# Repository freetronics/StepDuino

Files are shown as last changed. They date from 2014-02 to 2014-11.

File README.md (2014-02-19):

Freetronics StepDuino
=====================
Copyright 2013 Freetronics Pty Ltd  
Freetronics site:  www.freetronics.com  
Freetronics email: info@freetronics.com  

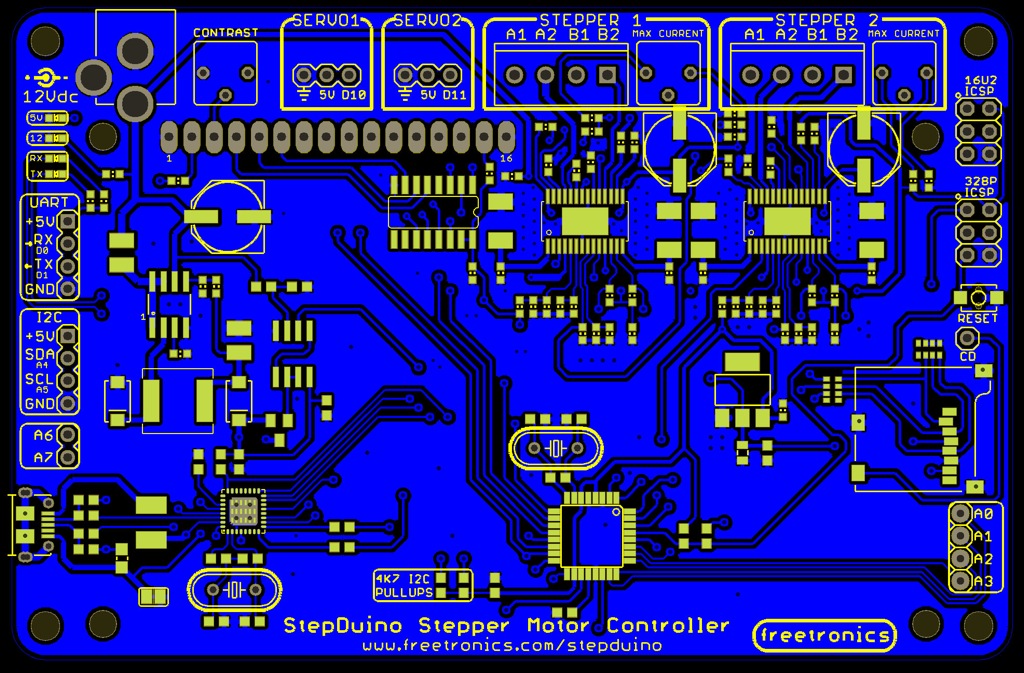
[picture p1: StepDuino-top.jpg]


The StepDuino is an Arduino-compatible board with two onboard stepper
motor drivers, a 20x4 LCD, servo outputs, and an SD card slot. This
makes it ideal for mechatronics projects such as small robots or 2D
plotters.

It uses the same ATmega328P MCU as the Arduino Uno reference design,
and includes an ATmega16u2 USB-to-serial converter just like the Uno.
You can therefore program it the same way as you would an Uno, but
with the benefit of all the extra features built in to the StepDuino.

Features:

 * 2 x 4-wire stepper motor drivers
 * 20x4 LCD
 * Micro SD card slot
 * Analog inputs for use with Nintendo DS touch screen or other sensors

You can view more online at:

  http://www.freetronics.com/stepduino

INSTALLATION
------------
The design is saved as an EAGLE project. EAGLE PCB design software is
available from www.cadsoftusa.com free for non-commercial use. To use
this project download it and place the directory containing these files
into the "eagle" directory on your computer. Then open EAGLE and
navigate to Projects -> eagle -> StepDuino.

DISTRIBUTION
------------
The specific terms of distribution of this project are governed by the
license referenced below.

LICENSE
-------
Licensed under the TAPR Open Hardware License (www.tapr.org/OHL).
The "license" folder within this repository also contains a copy of
this license in plain text format.

CREDITS
-------
Designed by Luke Weston (reindeerflotilla@gmail.com) and Jonathan Oxer
(jon@freetronics.com)

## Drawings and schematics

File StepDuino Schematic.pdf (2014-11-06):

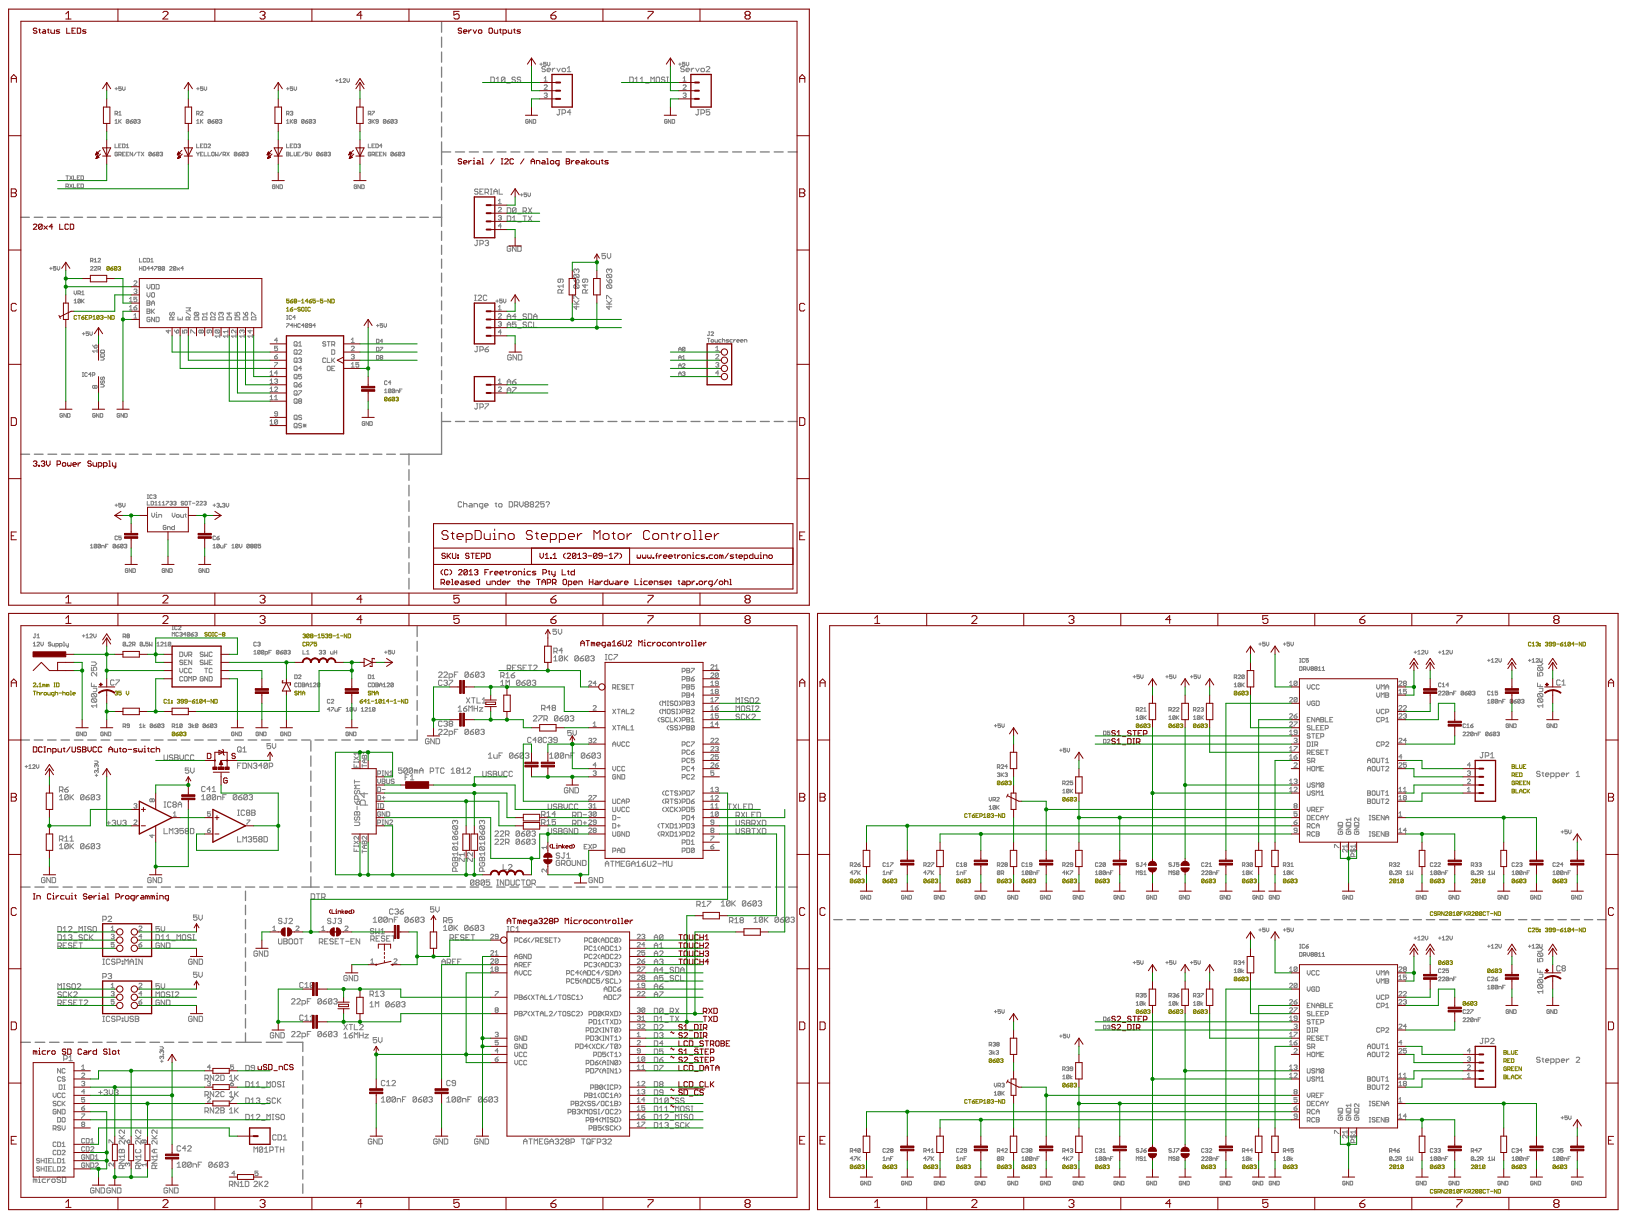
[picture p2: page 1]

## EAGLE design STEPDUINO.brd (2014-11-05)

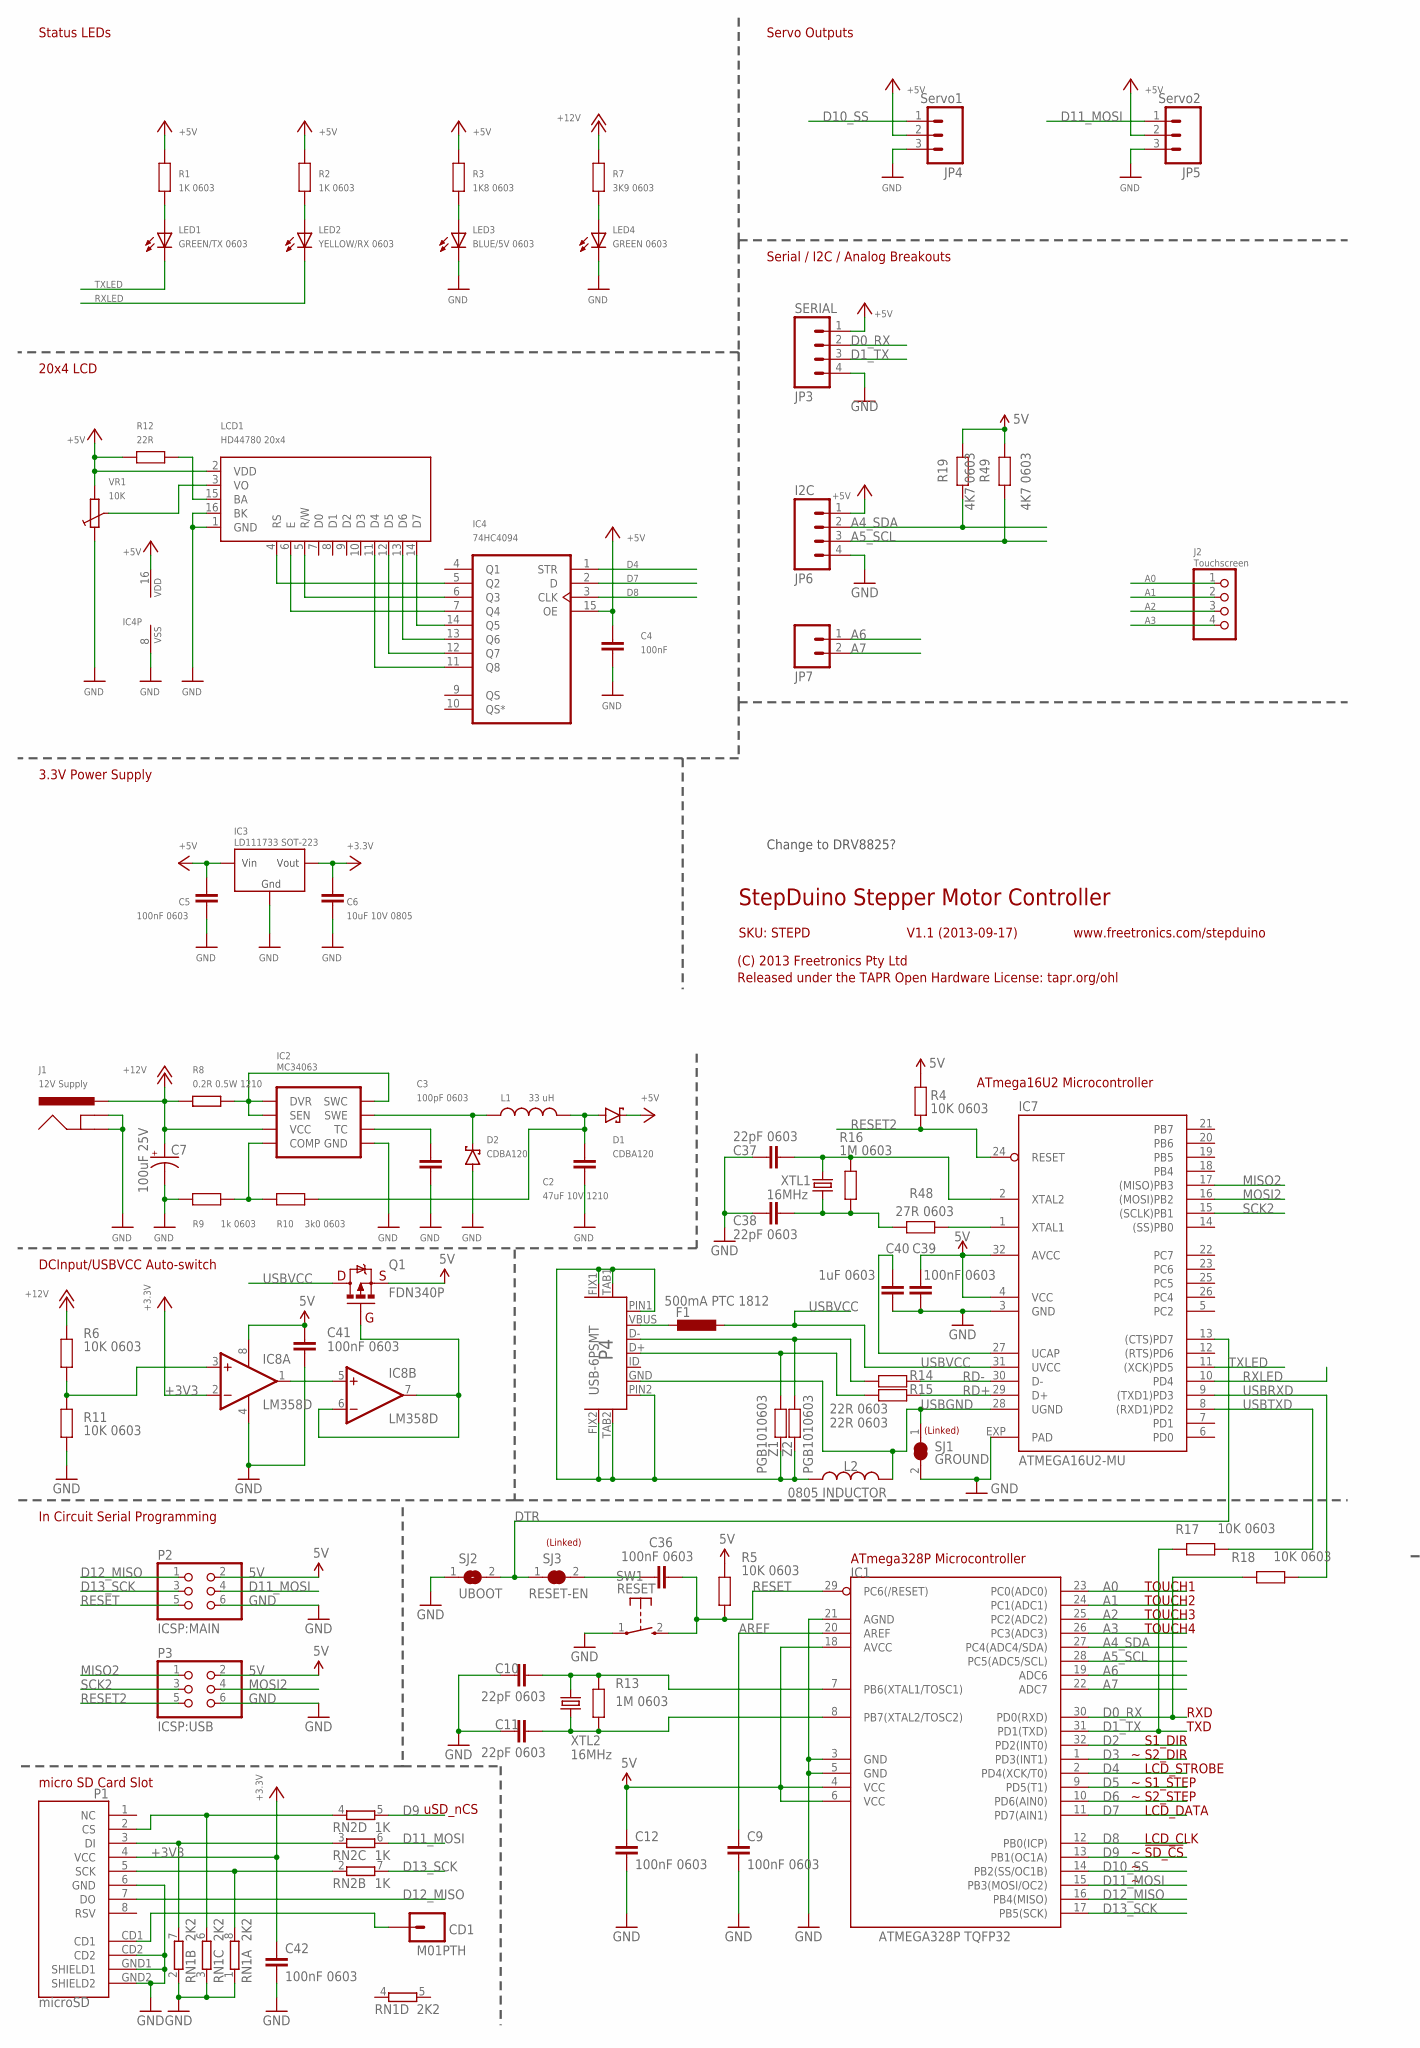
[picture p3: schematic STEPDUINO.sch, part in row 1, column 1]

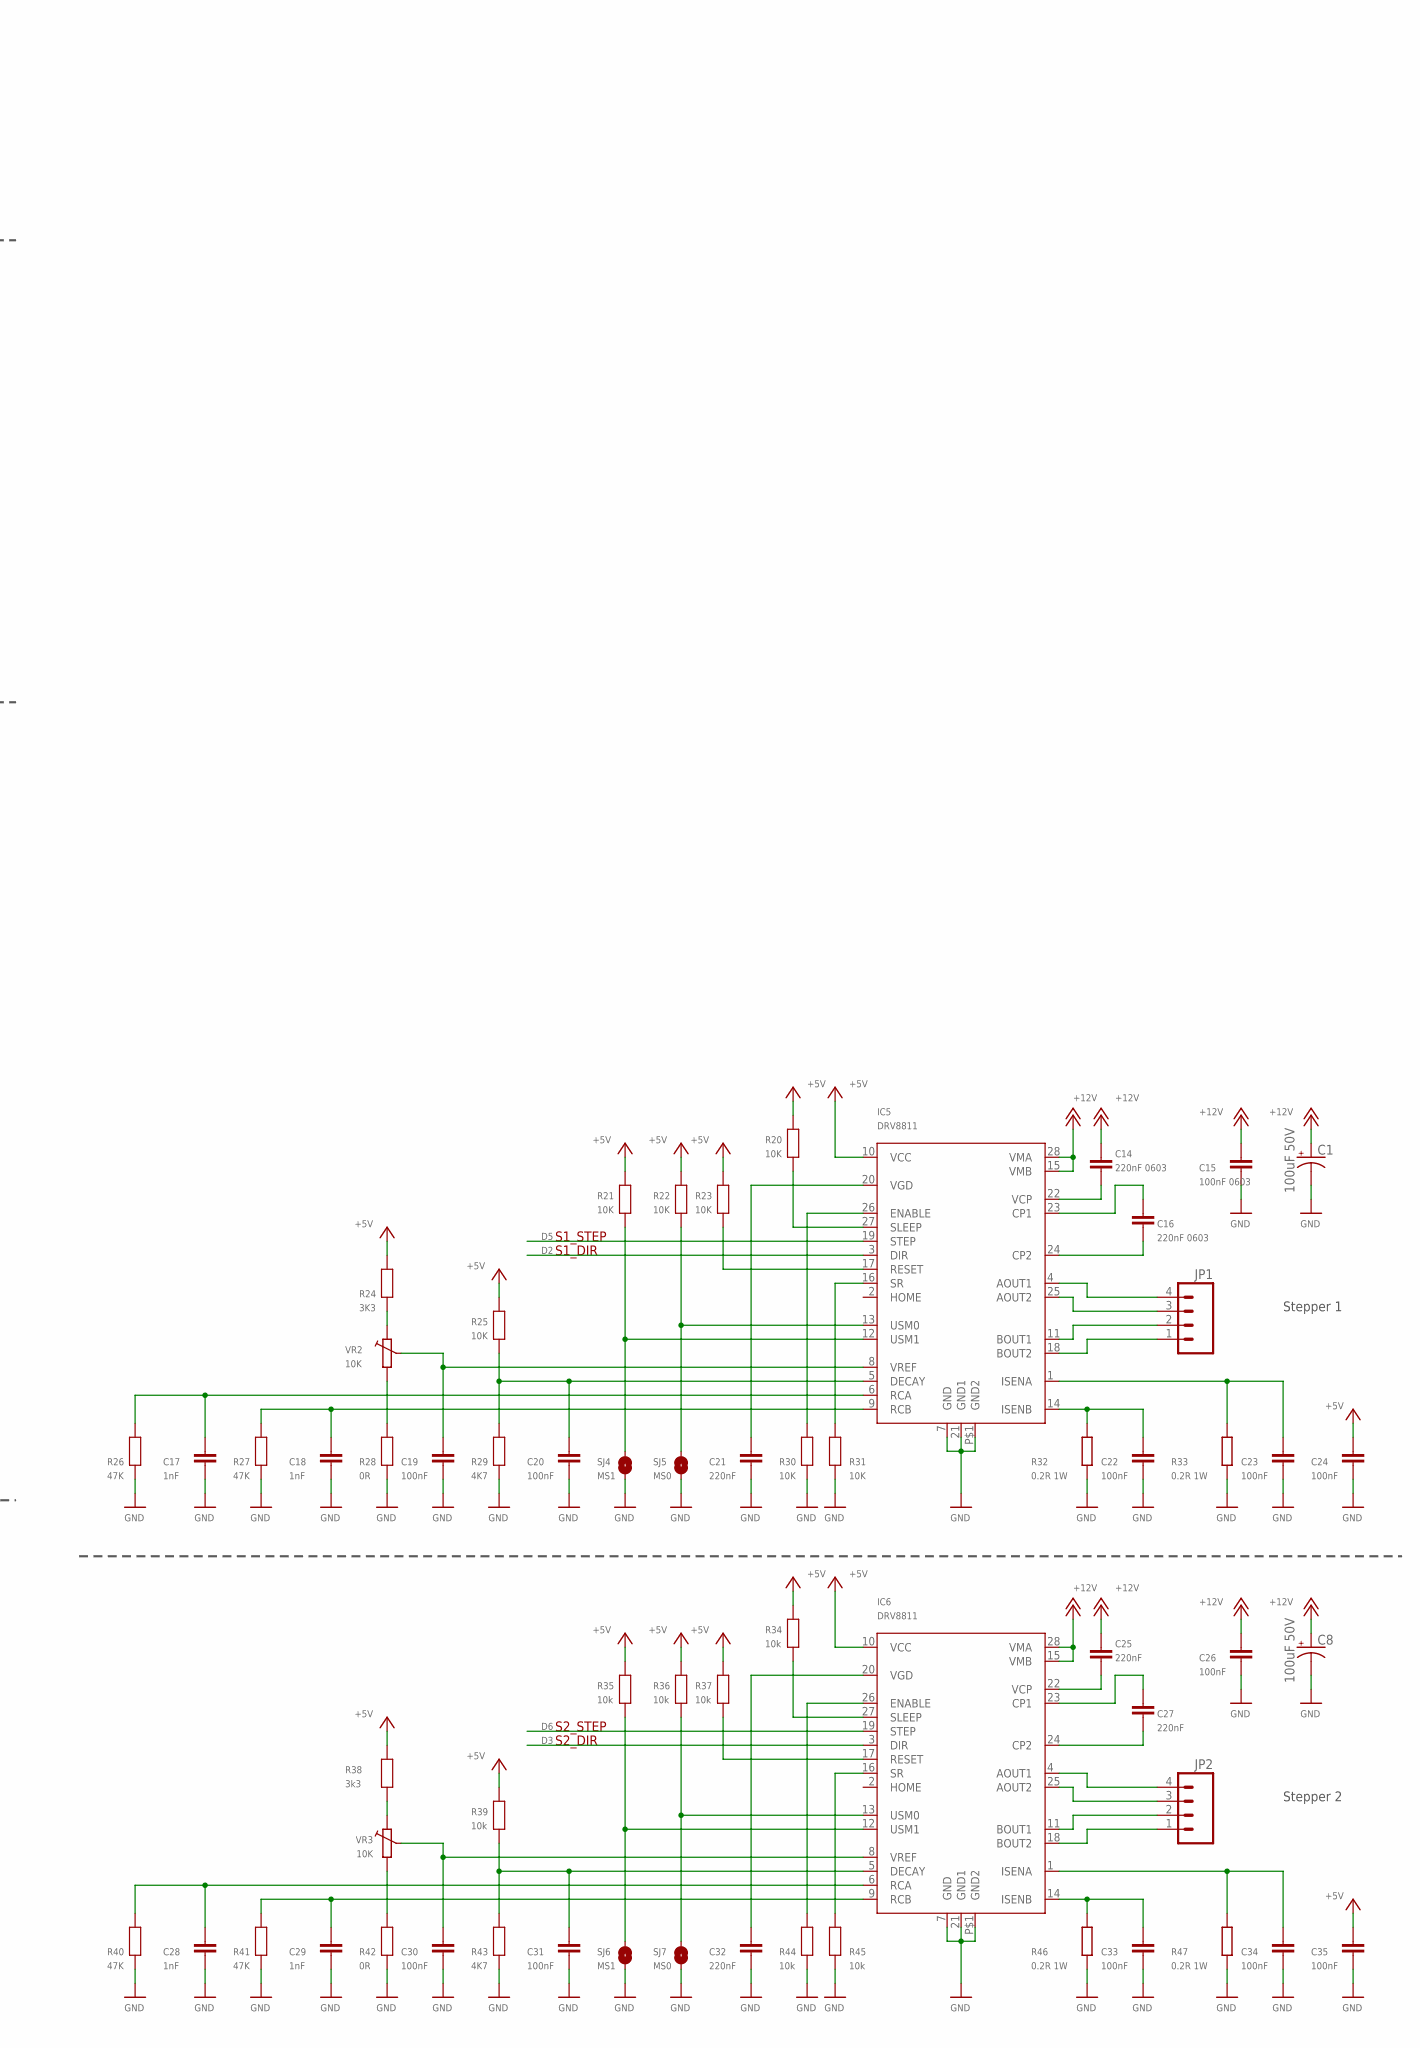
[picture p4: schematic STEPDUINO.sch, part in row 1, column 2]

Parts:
C1, C8: 100uF 50V; PANASONIC_E
C2: 47uF 10V 1210; C1210
C3: 100pF 0603; 0603
C4, C19, C20, C22, C23, C24, C26, C30, C31, C33, C34, C35: 100nF; 0603
C5, C9, C12, C15, C36, C39, C41, C42: 100nF 0603; 0603
C6: 10uF 10V 0805; 0805
C7: 100uF 25V; PANASONIC_E
C10, C11, C37, C38: 22pF 0603; 0603
C14, C16: 220nF 0603; 0603
C17, C18, C28, C29: 1nF; 0603
C21, C25, C27, C32: 220nF; 0603
C40: 1uF 0603; 0603
CD1: M01PTH; 1X01
D1, D2: CDBA120; SMA
F1: 500mA PTC 1812; L1812
IC1: ATMEGA328P TQFP32; TQFP32-08
IC2: MC34063; SO08
IC3: LD111733 SOT-223; SOT223
IC4: 74HC4094; SO16@1
IC5, IC6: DRV8811; HTSSOP28
IC7: ATMEGA16U2-MU; ATMEL_QFN32
IC8: LM358D; SO08
J1: 12V Supply; POWER_JACK_PTH
J2: Touchscreen; 1X04
JP1, JP2: M04SCREW; SCREWTERMINAL-3.5MM-4
JP3: SERIAL; 1X04
JP4: Servo1; 1X03
JP5: Servo2; 1X03
JP6: I2C; 1X04
JP7: M02PTH; 1X02
L1: 33 uH; CR75
L2: 0805 INDUCTOR; 0805-LARGE
LCD1: HD44780 20x4; HDM20416L
LED1: GREEN/TX 0603; LED-0603
LED2: YELLOW/RX 0603; LED-0603
LED3: BLUE/5V 0603; LED-0603
LED4: GREEN 0603; LED-0603
P1: microSD; MICRO-SD-SOCKET-PP
P2: ICSP:MAIN; 2X03
P3: ICSP:USB; 2X03
P4: USB-6PSMT; USB-MICROB-MB05PMXX
Q1: FDN340P; SOT23
R1, R2: 1K 0603; 0603
R3: 1K8 0603; 0603
R4, R5, R6, R11: 10K 0603; 0603
R7: 3K9 0603; 0603
R8: 0.2R 0.5W 1210; R1210
R9: 1k 0603; 0603
R10: 3k0 0603; 0603
R12: 22R; 0603
R13, R16: 1M 0603; 0603
R14, R15: 22R 0603; 0603
R17, R18: 10K 0603; 0603@1
R19, R49: 4K7 0603; 0603
R20, R21, R22, R23, R25, R30, R31: 10K; 0603
R24: 3K3; 0603
R26, R27, R40, R41: 47K; 0603
R28, R42: 0R; 0603
R29, R43: 4K7; 0603
R32, R33, R46, R47: 0.2R 1W; R2010
R34, R35, R36, R37, R39, R44, R45: 10k; 0603
R38: 3k3; 0603
R48: 27R 0603; 0603
RN1: 2K2; CAY16
RN2: 1K; CAY16
SJ1: GROUND; SJC
SJ2: UBOOT; SJ
SJ3: RESET-EN; SJC
SJ4, SJ6: MS1; SJ
SJ5, SJ7: MS0; SJ
SW1: RESET; TACTILE_SWITCH_SMD_2PIN_TINY
VR1, VR2, VR3: 10K; CT6
XTL1, XTL2: 16MHz; HC49U-V
Z1, Z2: PGB1010603; 0603

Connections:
5V: C4.1, C5.1, C12.1, C24.1, C35.1, C39.1, C41.1, D1.K, IC1.4 (VCC), IC1.6 (VCC), IC1.18 (AVCC), IC3.3 (VIN), IC4.15 (OE), IC4.16 (VDD), IC5.10 (VCC), IC6.10 (VCC), IC7.4 (VCC), IC7.32 (AVCC), IC8.8 (V+), JP3.1, JP4.2, JP5.2, JP6.1, LCD1.2 (VDD), P2.2, P3.2, Q1.2 (S), R1.2, R2.2, R3.2, R4.2, R5.2, R12.2, R19.2, R20.2, R21.2, R22.2, R23.2, R24.2, R25.2, R34.2, R35.2, R36.2, R37.2, R38.2, R39.2, R49.2, VR1.A
+3V3: C6.1, C42.1, IC3.2 (VOUT), IC8.2 (-IN), P1.4 (VCC)
+12V: C1.+, C7.+, C8.+, C14.1, C15.1, C25.1, C26.1, IC2.6 (VCC), IC5.15 (VMB), IC5.28 (VMA), IC6.15 (VMB), IC6.28 (VMA), J1.PWR, R6.2, R7.2, R8.1
A0: IC1.23 (PC0(ADC0)), J2.1
A1: IC1.24 (PC1(ADC1)), J2.2
A2: IC1.25 (PC2(ADC2)), J2.3
A3: IC1.26 (PC3(ADC3)), J2.4
A4_SDA: IC1.27 (PC4(ADC4/SDA)), JP6.2, R19.1
A5_SCL: IC1.28 (PC5(ADC5/SCL)), JP6.3, R49.1
A6: IC1.19 (ADC6), JP7.1
A7: IC1.22 (ADC7), JP7.2
AREF: C9.1, IC1.20 (AREF)
D0_RX: IC1.30 (PD0(RXD)), JP3.2, R18.1
D1_TX: IC1.31 (PD1(TXD)), JP3.3, R17.1
D2: IC1.32 (PD2(INT0)), IC5.3 (DIR)
D3: IC1.1 (PD3(INT1)), IC6.3 (DIR)
D4: IC1.2 (PD4(XCK/T0)), IC4.1 (STR)
D5: IC1.9 (PD5(T1)), IC5.19 (STEP)
D6: IC1.10 (PD6(AIN0)), IC6.19 (STEP)
D7: IC1.11 (PD7(AIN1)), IC4.2 (D)
D8: IC1.12 (PB0(ICP)), IC4.3 (CLK)
D9: IC1.13 (PB1(OC1A)), RN2.5 (2)
D10_SS: IC1.14 (PB2(SS/OC1B)), JP4.1
D11_MOSI: IC1.15 (PB3(MOSI/OC2)), JP5.1, P2.4, RN2.6 (2)
D12_MISO: IC1.16 (PB4(MISO)), P1.7 (DO), P2.1
D13_SCK: IC1.17 (PB5(SCK)), P2.3, RN2.7 (2)
DTR: IC7.13 ((CTS)PD7), SJ2.2, SJ3.1
GND: C1.-, C2.2, C3.2, C4.2, C5.2, C6.2, C7.-, C8.-, C9.2, C10.1, C11.1, C12.2, C15.2, C17.2, C18.2, C19.2, C20.2, C21.2, C22.2, C23.2, C24.2, C26.2, C28.2, C29.2, C30.2, C31.2, C32.2, C33.2, C34.2, C35.2, C37.1, C38.1, C39.2, C40.2, C41.2, C42.2, D2.A, IC1.3 (GND), IC1.5 (GND), IC1.21 (AGND), IC2.4 (GND), IC3.1 (GND), IC4.8 (VSS), IC5.7 (GND), IC5.21 (GND1), IC5.P$1 (GND2), IC6.7 (GND), IC6.21 (GND1), IC6.P$1 (GND2), IC7.3 (GND), IC7.EXP (PAD), IC8.4 (V-), J1.GND, J1.GNDBREAK, JP3.4, JP4.3, JP5.3, JP6.4, LCD1.1 (GND), LCD1.16 (BK), LED3.C, LED4.C, P1.6 (GND), P1.CD2, P1.GND1 (SHIELD1), P1.GND2 (SHIELD2), P2.6, P3.6, R9.2, R11.1, R26.1, R27.1, R28.1, R29.1, R30.1, R31.1, R32.1, R33.1, R40.1, R41.1, R42.1, R43.1, R44.1, R45.1, R46.1, R47.1, RN1.1, RN1.2 (1), RN1.3 (1), SJ1.2, SJ2.1, SJ4.1, SJ5.1, SJ6.1, SJ7.1, SW1.1, VR1.E
MISO2: IC7.17 ((MISO)PB3), P3.1
MOSI2: IC7.16 ((MOSI)PB2), P3.4
unnamed: IC6.11 (BOUT1), JP2.2
unnamed: IC5.4 (AOUT1), JP1.4
unnamed: IC6.18 (BOUT2), JP2.1
unnamed: IC6.25 (AOUT2), JP2.3
unnamed: C27.2, IC6.24 (CP2)
unnamed: C27.1, IC6.23 (CP1)
unnamed: C25.2, IC6.22 (VCP)
unnamed: C32.1, IC6.20 (VGD)
unnamed: C10.2, IC1.7 (PB6(XTAL1/TOSC1)), R13.2, XTL2.2
unnamed: C34.1, IC6.1 (ISENA), R47.2
unnamed: C33.1, IC6.14 (ISENB), R46.2
unnamed: C31.1, IC6.5 (DECAY), R39.1, R43.2
unnamed: C28.1, IC6.6 (RCA), R40.2
unnamed: C16.2, IC5.24 (CP2)
unnamed: C16.1, IC5.23 (CP1)
unnamed: IC5.16 (SR), R31.2
unnamed: C29.1, IC6.9 (RCB), R41.2
unnamed: IC5.18 (BOUT2), JP1.1
unnamed: IC5.11 (BOUT1), JP1.2
unnamed: IC5.25 (AOUT2), JP1.3
unnamed: C14.2, IC5.22 (VCP)
unnamed: C20.1, IC5.5 (DECAY), R25.1, R29.2
unnamed: C21.1, IC5.20 (VGD)
unnamed: C17.1, IC5.6 (RCA), R26.2
unnamed: C11.2, IC1.8 (PB7(XTAL2/TOSC2)), R13.1, XTL2.1
unnamed: LED3.A, R3.1
unnamed: LED2.A, R2.1
unnamed: LED1.A, R1.1
unnamed: IC2.1 (SWC), IC2.7 (SEN), IC2.8 (DVR), R8.2
unnamed: IC7.1 (XTAL1), R48.1
unnamed: L2.1, P4.FIX1, P4.FIX2, P4.PIN1, P4.PIN2, P4.TAB1, P4.TAB2, Z1.2, Z2.2
unnamed: P4.D+, R15.2, Z1.1
unnamed: P4.D-, R14.2, Z2.1
unnamed: LED4.A, R7.1
unnamed: C3.1, IC2.3 (TC)
unnamed: IC2.5 (COMP), R9.1, R10.2
unnamed: D2.K, IC2.2 (SWE), L1.P$1 (1)
unnamed: C23.1, IC5.1 (ISENA), R33.2
unnamed: C22.1, IC5.14 (ISENB), R32.2
unnamed: C18.1, IC5.9 (RCB), R27.2
unnamed: IC5.27 (SLEEP), R20.1
unnamed: IC4.5 (Q2), LCD1.4 (RS)
unnamed: IC4.6 (Q3), LCD1.5 (R/W)
unnamed: IC4.7 (Q4), LCD1.6 (E)
unnamed: IC4.11 (Q8), LCD1.11 (D4)
unnamed: IC4.12 (Q7), LCD1.12 (D5)
unnamed: IC4.13 (Q6), LCD1.13 (D6)
unnamed: IC4.14 (Q5), LCD1.14 (D7)
unnamed: IC5.17 (RESET), R23.1
unnamed: LCD1.3 (VO), VR1.S
unnamed: LCD1.15 (BA), R12.1
unnamed: R24.1, VR2.E
unnamed: R28.2, VR2.A
unnamed: IC8.3 (+IN), R6.1, R11.2
unnamed: IC8.6 (-IN), IC8.7 (OUT), Q1.1 (G)
unnamed: C19.1, IC5.8 (VREF), VR2.S
unnamed: IC5.26 (ENABLE), R30.2
unnamed: IC5.12 (USM1), R21.1, SJ4.2
unnamed: IC5.13 (USM0), R22.1, SJ5.2
unnamed: IC6.27 (SLEEP), R34.1
unnamed: IC6.17 (RESET), R37.1
unnamed: R38.1, VR3.E
unnamed: R42.2, VR3.A
unnamed: C30.1, IC6.8 (VREF), VR3.S
unnamed: IC6.26 (ENABLE), R44.2
unnamed: IC6.12 (USM1), R35.1, SJ6.2
unnamed: IC6.13 (USM0), R36.1, SJ7.2
unnamed: IC6.16 (SR), R45.2
unnamed: IC6.4 (AOUT1), JP2.4
unnamed: IC8.1 (OUT), IC8.5 (+IN)
unnamed: P1.2 (CS), RN1.6 (2), RN2.4 (1)
unnamed: P1.3 (DI), RN1.7 (2), RN2.3 (1)
unnamed: P1.5 (SCK), RN1.8 (2), RN2.2 (1)
unnamed: CD1.1, P1.CD1
unnamed: C36.1, SJ3.2
unnamed: C37.2, IC7.2 (XTAL2), R16.2, XTL1.2
unnamed: C38.2, R16.1, R48.2, XTL1.1
unnamed: F1.1, P4.VBUS
unnamed: C40.1, IC7.27 (UCAP)
RD+: IC7.29 (D+), R15.1
RD-: IC7.30 (D-), R14.1
REG_5V: C2.1, D1.A, L1.P$2 (2), R10.1
RESET: C36.2, IC1.29 (PC6(/RESET)), P2.5, R5.1, SW1.2 (S)
RESET2: IC7.24 (RESET), P3.5, R4.1
RXLED: IC7.10 (PD4), LED2.C
SCK2: IC7.15 ((SCLK)PB1), P3.3
TXLED: IC7.11 ((XCK)PD5), LED1.C
USBGND: IC7.28 (UGND), L2.2, P4.GND, SJ1.1
USBRXD: IC7.9 ((TXD1)PD3), R18.2
USBTXD: IC7.8 ((RXD1)PD2), R17.2
USBVCC: F1.2, IC7.31 (UVCC), Q1.3 (D)

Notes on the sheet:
StepDuino Stepper Motor Controller
V1.1 (2013-09-17)
(C) 2013 Freetronics Pty Ltd
Released under the TAPR Open Hardware License: tapr.org/ohl
www.freetronics.com/stepduino
Stepper 1
Stepper 2
ATmega328P Microcontroller
ATmega16U2 Microcontroller
DCInput/USBVCC Auto-switch
uSD_nCS
In Circuit Serial Programming
micro SD Card Slot
(Linked)
!SD_CS
TOUCH1
TOUCH2
TOUCH3
TOUCH4
TXD
RXD
S1_DIR
S2_DIR
S2_STEP
S1_STEP
LCD_CLK
LCD_DATA
LCD_STROBE
Change to DRV8825?
SKU: STEPD
Serial / I2C / Analog Breakouts
Servo Outputs
3.3V Power Supply
20x4 LCD
Status LEDs

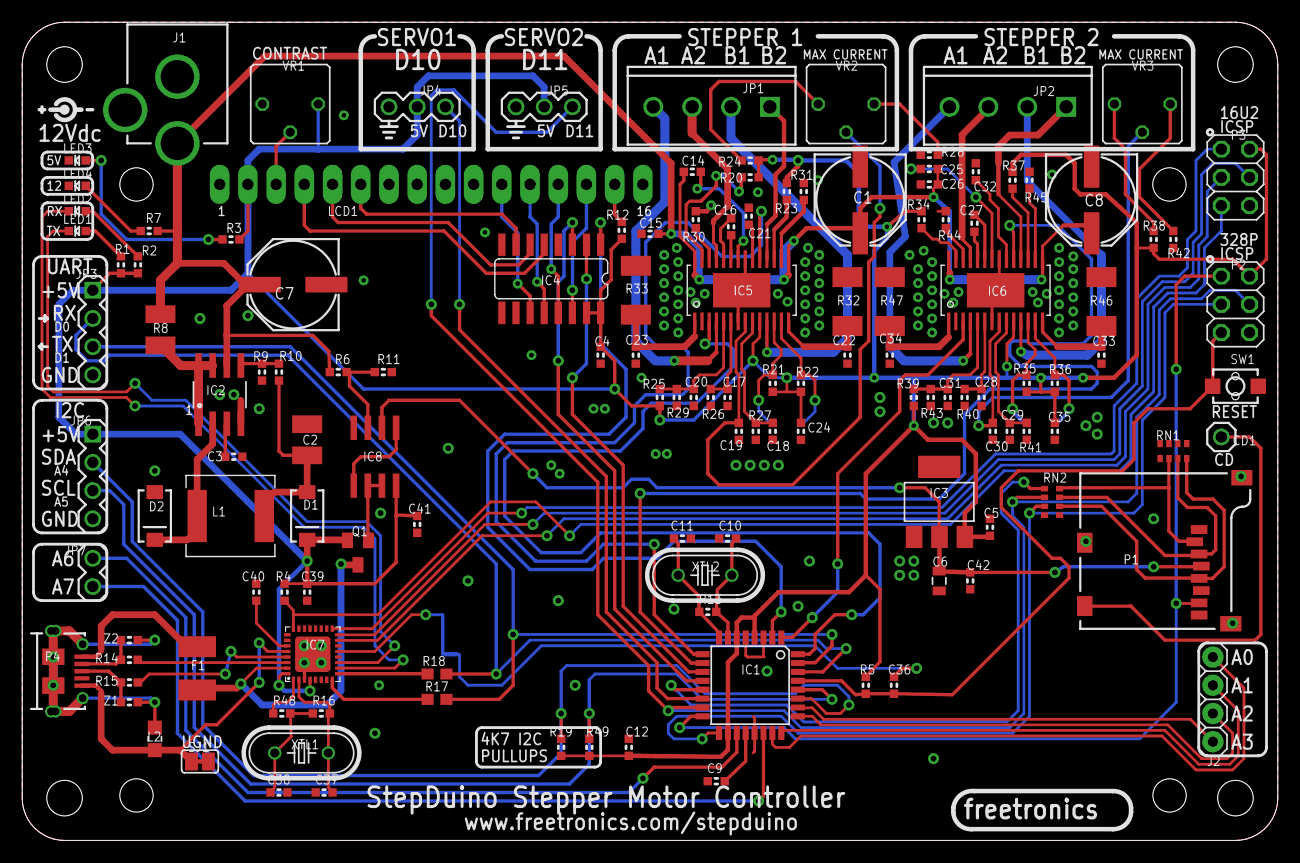
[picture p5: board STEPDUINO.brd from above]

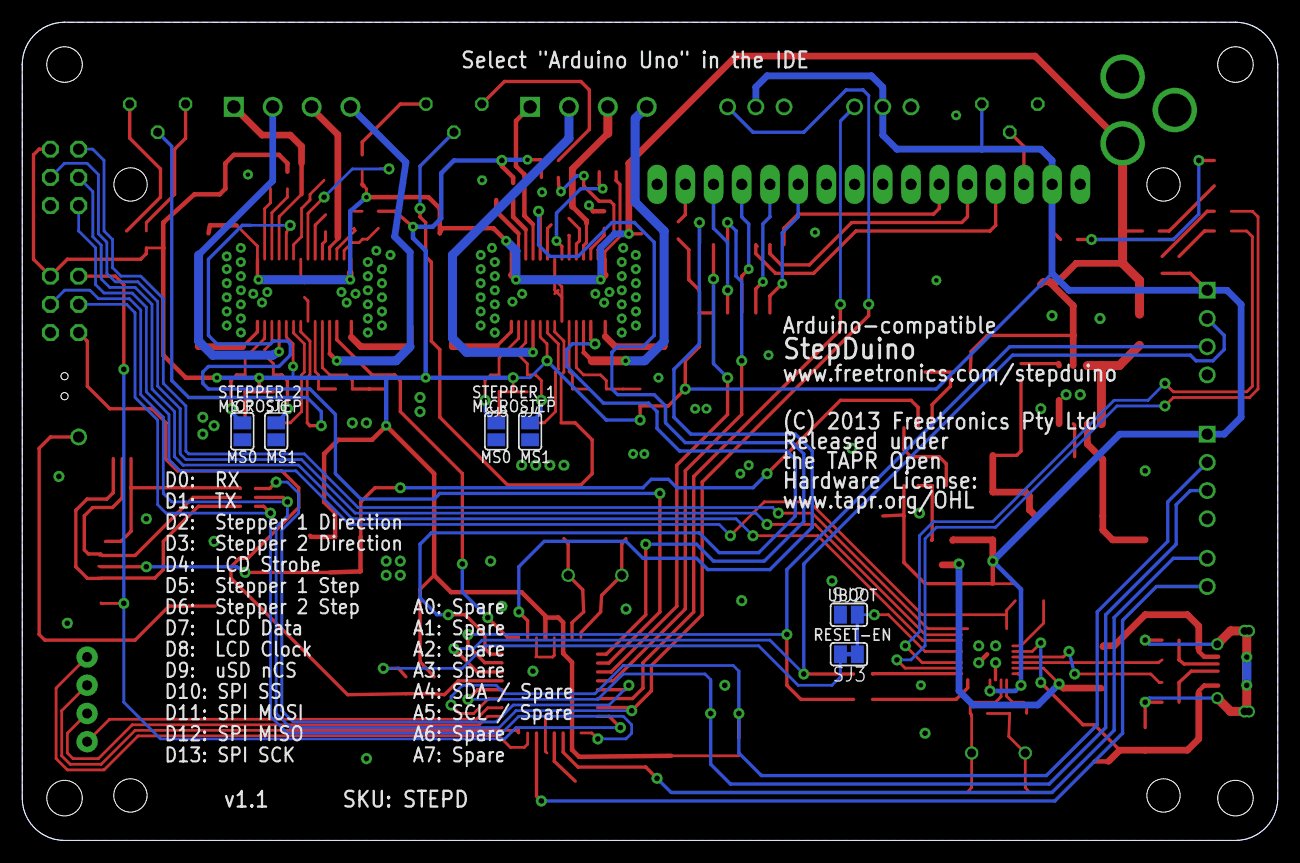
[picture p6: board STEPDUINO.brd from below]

Board: 2 copper layers, 113.0 x 73.7 mm, 140 parts (6 on the bottom side), 121 nets.

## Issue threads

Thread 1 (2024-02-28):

Eagle design files link

Anacapala, 2024-02-28:
The link for EAGLE PCB design software in the documentation is out of date. The link should now be:
https://www.autodesk.com/ca-en/products/fusion-360/trial-intake
or similar.   As Eagle files will be unsupported from 2026 there should be an issue raised to convert the design files to KiCad.

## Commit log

2013-04-08 Removed CNCPlotter files
    [CNCPlotter.GBL, CNCPlotter.GBS, CNCPlotter.GTL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]
2013-04-08 Renamed project files
    [STEPDUINO.brd, STEPDUINO.sch]
2013-04-08 Start of major restructure using ATmega328
    [STEPDUINO.brd, STEPDUINO.sch]
2013-08-05 Routing for v1.0 release
    [STEPDUINO.brd, STEPDUINO.sch]
2014-02-19 Added documentation and preview image
    [STEPDUINO.brd, STEPDUINO.sch]
2014-11-05 Made 0603 resistor and capacitor footprints consistent
    [STEPDUINO.brd, STEPDUINO.sch]
2014-11-06 Add PDF schematic

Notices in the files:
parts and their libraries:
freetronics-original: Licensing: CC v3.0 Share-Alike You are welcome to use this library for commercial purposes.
